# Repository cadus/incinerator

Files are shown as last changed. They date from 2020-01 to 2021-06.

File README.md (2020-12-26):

# Firmware & electronics for the CADUS incinerator

Furnace for the incineration of medical waste.

[][1]

  [PlatformIO CI]: https://github.com/cadus/incinerator/workflows/PlatformIO%20CI/badge.svg
  [1]: https://github.com/cadus/incinerator/actions?query=workflow%3A%22PlatformIO+CI%22

## [Project documentation on GitHub pages]

  [Project documentation on GitHub pages]: https://cadus.github.io/incinerator/

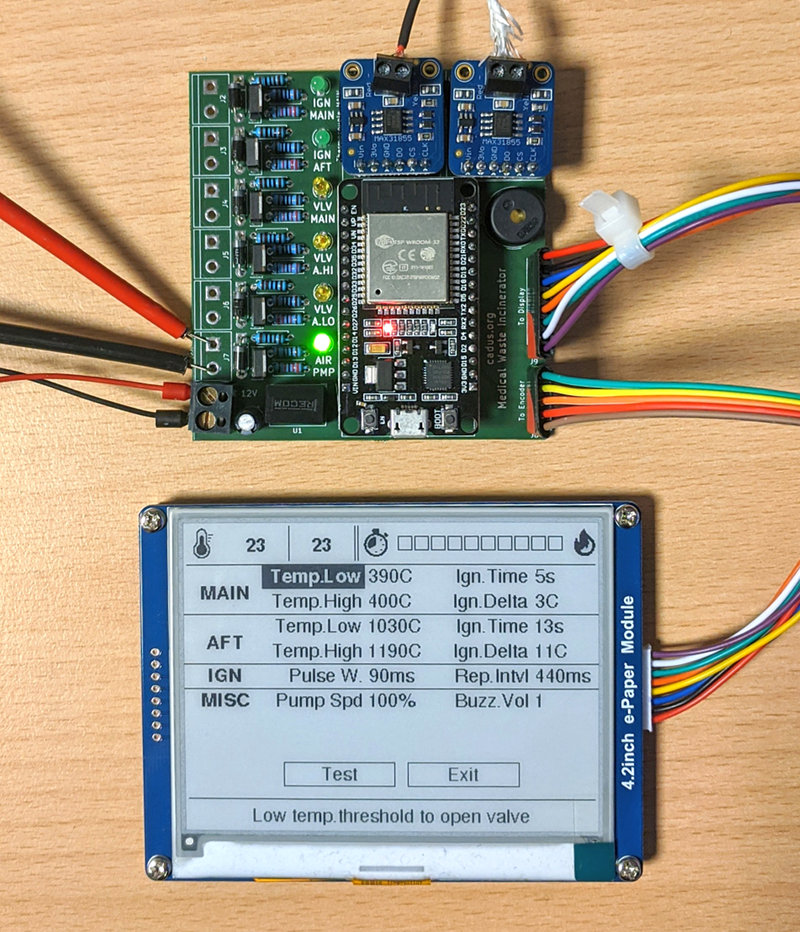
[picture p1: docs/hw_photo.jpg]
Hardware Photo


**Under construction / Work in progress**

Open Source Hardware

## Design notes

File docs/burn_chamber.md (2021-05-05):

# Burn chamber
The burn chamber is responsible for managing the burn process in one burn chamber, which includes triggering ignition, reading temperature and controlling gas flow via valves.

### Temperature control
The temperature is controlled with gas valves which can be ON or OFF (no gradual control). The main and afterburner chamber feature a single valve each (VALVE_MAIN,VALVE_AFT).

- When temperature sinks below T_MIN, VALVE_MAIN / VALVE_AFT is activated.
- When temperature rises above T_MAX, VALVE_MAIN / VALVE_AFT is deactivated.

### State machine
``` mermaid
stateDiagram-v2
  [*] --> start: Burn start requested
  start --> waitIgnition: Set gas valve, request ignition
  waitIgnition --> failed: Ignition failed
  failed --> [*]: Reset
  waitIgnition --> waitTemp: Ignition successful
  waitTemp --> burnHigh: T_MIN reached
  burnHigh --> burnLow: T > T_MAX
  burnLow --> waitBurnHigh: T < T_MIN, ignite again
  waitBurnHigh --> burnHigh: Ignition successful
  waitBurnHigh --> failed: Ignition failed
  burnHigh --> [*]: Reset
  burnLow --> [*]: Reset
```

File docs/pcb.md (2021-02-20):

# PCB schematic

SVG file

## Encoder wiring

SVG file

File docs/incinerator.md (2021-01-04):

# Incinerator
The incinerator is responsible for managing the overall burn process.

### Burn sequence
- Start burn process in afterburner to pre-heat it
- When afterburner has reached operating temperature, enable air pump and main burner.
- When main burner has reached operating temp., wait until burn time is elapsed.
- Switch off gas and wait until system has cooled down.

### State machine
``` mermaid
stateDiagram-v2
  [*] --> start: Burn start requested
  start --> waitAfterburner: Start afterburner
  waitAfterburner --> failureCoolDown: Aft. failed
  waitAfterburner --> startMain: Aft. temp. reached
  waitAfterburner --> abortCoolDown: User abort
  startMain --> waitMain: Start main burner
  waitMain --> burnActive: Main temp. reached
  waitMain --> failureCoolDown: Main failed
  waitMain --> abortCoolDown: User abort
  burnActive --> coolDown: Burn time elapsed
  burnActive --> failureCoolDown: Burner failed
  burnActive --> abortCoolDown: User abort
  coolDown --> [*]: System cooled down
  failureCoolDown --> [*]: System cooled down
  abortCoolDown --> [*]: System cooled down
```

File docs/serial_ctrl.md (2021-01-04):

# Serial control

On the ESP32 serial port, there's a simple command line interface implemented.

## Serial commands

| Command | Argument | Description |
|---|---|---|
| `TM` | deg. C | Simulate main burner temperature |
| `TA` | deg. C | Simulate afterburner temperature |
| `SS` | | Create screenshot |

## Temperature simulation

The temperature of the burn chambers can be simulated to facilitate testing of the incineration logic w/o actual burning.
To enable temperature simulation, the firmware needs to be built with `-DENABLE_TEMP_SIMULATION`.

### Temperature simulation tool

The script `temp_sim.py` can be used to conduct temperature simulation while testing.
The keys `e`, `r`, `d`, `f` and `u`, `i`, `j`, `k` lower or raise the main and afterburner temperature, respectively.

## Screenshots

`SS` creates a screenshot. It prints out a base64-encoding of a PNM file containing the current screen contents.

The base64 dump can be easily converted to a PNG file using the following shell snippet (needs imagemagick to work):
```
base64 -d | convert pnm:- screenshot.png
```

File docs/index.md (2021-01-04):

# CADUS incinerator
Furnace for the incineration of medical waste.

## Project scope
This project contains the firmware & schematic for the control module of the [CADUS](https://www.cadus.org) incinerator.

## Hardware
The control module is based on this ESP32 board: [DEBO JT ESP32 NodeMCU](https://www.reichelt.de/nodemcu-esp32-wifi-und-bluetooth-modul-debo-jt-esp32-p219897.html) similar to [DOIT ESP32 DEVKIT V1](http://elektro.turanis.de/html/prj135/esp32_pinout.png).  
KiCad project covering the schematic of the motherboard carrying the ESP32 is included in the `pcb` folder.

## Build Prerequisites
Install [PlatformIO IDE](https://platformio.org/platformio-ide) or [PlatformIO Core (CLI)](https://docs.platformio.org/en/latest/installation.html#installation-methods)  
PlatformIO will take care of the Arduino framework and third-party libraries.

## Build
PlatformIO IDE: Click "Build"  
PlatformIO CLI:
```
pio run
```

## Install
Connect ESP32 board via USB. Check the serial port assigned to the board, adapt `upload_port` in `platformio.ini`, if necessary.

PlatformIO IDE: Click "Upload"  
PlatformIO CLI:
```
pio run --target upload
```

## Update via esptool
Install esptool with `pip3 install --user esptool`.

Connect the processor module via USB and determine the USB serial port. (`/dev/ttyUSB0` in this example)

Update the firmware:
```
python3 -m esptool --port /dev/ttyUSB0 --baud 921600 write_flash 0x10000 firmware.bin
```

## Update via flasher
The flasher (distributed with releases) is a small wrapper around `esptool` and can be used for the update instead of calling `esptool` directly.

Using the flasher tool on windows:

* Install CP210x_VCP_Windows driver from https://www.silabs.com/developers/usb-to-uart-bridge-vcp-drivers
* Install Python3 https://www.python.org/downloads/windows/
  (Select "add python to PATH")
* Open terminal in flasher directory
* Enter "pip install esptool pyserial" (only necessary when doing this for the first time)
* Enter "flasher.py"
* Choose serial port (use the one called "Silicon Labs CP210x")
* Hold down the BOOT button on the processor board (right from the USB socket)
* Wait until flasher is finished

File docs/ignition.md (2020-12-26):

# Ignition module
Ignition is triggered from higher level control (burn chamber).

### Ignition control
Ignition coil is activated for a configurable time `ign_pulse_w`, this is repeated after a configurable delay `ign_repeat_itvl` until temperature has risen enough that a successful ignition can be assumed.

### Protection logic
Ignition control features a simple protection logic to make sure there's no gas flow when the gas is not burning. After ignition has started, the ignition module checks if temperature has risen by a configurable delta `ign_delta`. When a configurable timeout `ign_t` has elapsed w/o temperature rising, then the ignition module indicates that ignition has failed and the gas flow should be shut down.

### State machine
``` mermaid
stateDiagram-v2
  [*] --> setCoil: Ignition request
  setCoil --> waitPulse
  waitPulse --> resetCoil: ign_pulse_w elapsed
  resetCoil --> waitIgnition
  waitIgnition --> setCoil: ign_repeat_itvl elapsed
  waitIgnition --> success: Temp. raised
  waitIgnition --> failure: Timeout
  success --> [*]: Reset
  failure --> [*]: Reset
```

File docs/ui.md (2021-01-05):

# User interface

## Home screen

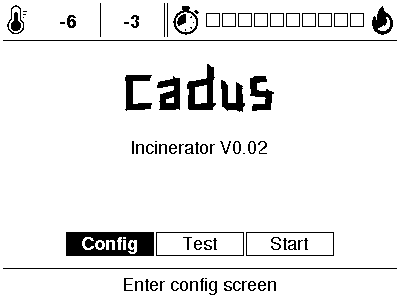
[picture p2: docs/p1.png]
home-screen


## Start screen

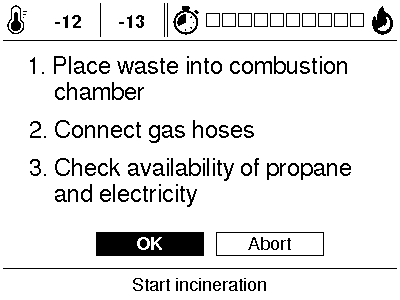
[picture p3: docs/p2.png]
start-screen


## Time entry

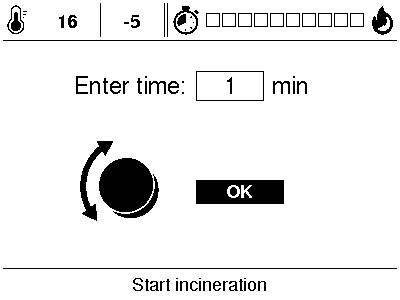
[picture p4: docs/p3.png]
time-entry


## Confirmation screen

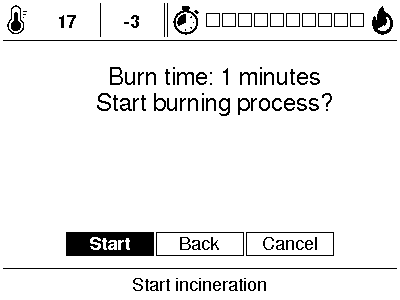
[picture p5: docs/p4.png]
confirmation-screen


## Burn screen

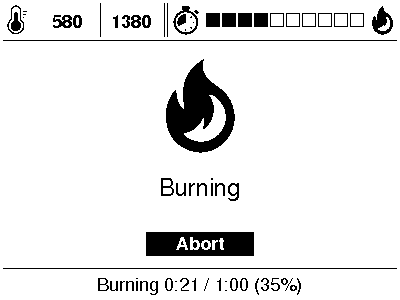
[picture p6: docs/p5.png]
burn-screen


## Cooldown screen
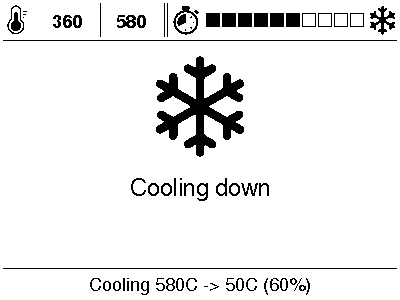
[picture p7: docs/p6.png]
cooldown-screen


## Cooldown finished
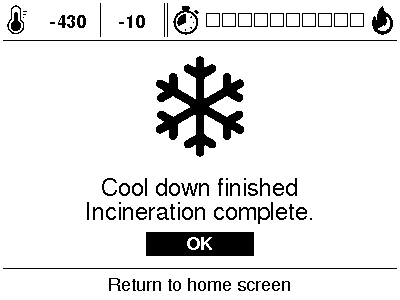
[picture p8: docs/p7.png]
cooldown-finished


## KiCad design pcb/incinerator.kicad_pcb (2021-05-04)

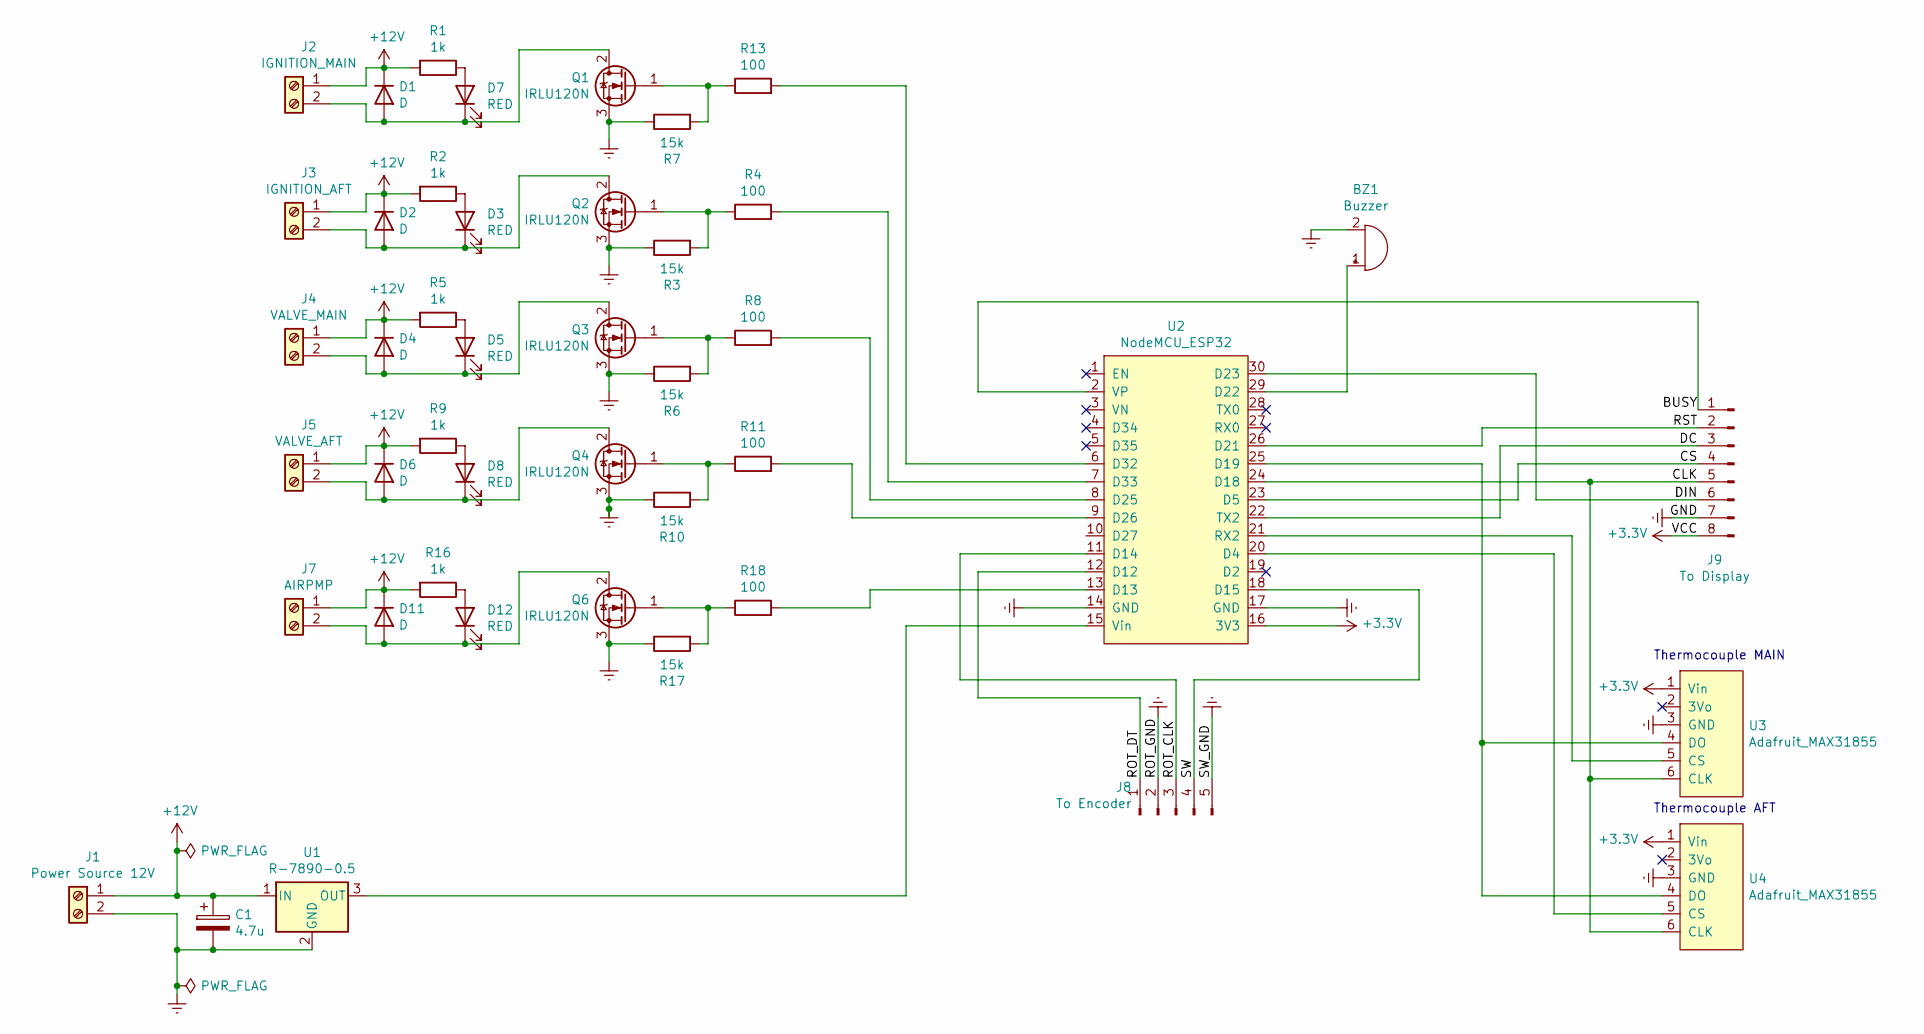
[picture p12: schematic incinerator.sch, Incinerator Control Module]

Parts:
BZ1: Buzzer; Buzzer_TDK_PS1240P02BT_D12.2mm_H6.5mm
C1: 4.7u; CP_Radial_D5.0mm_P2.50mm
D1, D2, D4, D6, D11: D; D_DO-41_P7.62mm_Custom
D3, D5, D7, D8, D12: RED; LED_D3.0mm_Custom
J1: Power Source 12V; TerminalBlock_bornier-2_P5.08mm
J2: IGNITION_MAIN; TerminalBlock_bornier-2_P5.08mm
J3: IGNITION_AFT; TerminalBlock_bornier-2_P5.08mm
J4: VALVE_MAIN; TerminalBlock_bornier-2_P5.08mm
J5: VALVE_AFT; TerminalBlock_bornier-2_P5.08mm
J7: AIRPMP; TerminalBlock_bornier-2_P5.08mm
J8: To Encoder; PinHeader_1x05_P2.54mm_Vertical
J9: To Display; PinHeader_1x08_P2.54mm_Vertical
Q1, Q2, Q3, Q4, Q6: IRLU120N; SIPAK_Vertical_Custom
R1, R2, R5, R9, R16: 1k; R_THT_D2.5mm_P7.62mm_Custom
R3, R6, R7, R10, R17: 15k; R_THT_D2.5mm_P7.62mm_Custom
R4, R8, R11, R13, R18: 100; R_THT_D2.5mm_P7.62mm_Custom
U1: R-7890-0.5; Converter_DCDC_RECOM_R-78E-0.5_THT
U2: NodeMCU_ESP32; ESP32_NodeMCU
U3, U4: Adafruit_MAX31855

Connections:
+3V3: J9.8, U2.16 (3V3), U3.1 (Vin), U4.1 (Vin)
+12V: C1.1, D1.1 (K), D2.1 (K), D4.1 (K), D6.1 (K), D11.1 (K), J1.1, J2.1, J3.1, J4.1, J5.1, J7.1, R1.2, R2.2, R5.2, R9.2, R16.2, U1.1 (IN)
/BUSY: J9.1, U2.2 (VP)
/CLK: J9.5, U2.24 (D18), U3.6 (CLK), U4.6 (CLK)
/CS: J9.4, U2.23 (D5)
/DC: J9.3, U2.22 (TX2)
/DIN: J9.6, U2.30 (D23)
/ROT_CLK: J8.3, U2.11 (D14)
/ROT_DT: J8.1, U2.12 (D12)
/RST: J9.2, U2.26 (D21)
/SW: J8.4, U2.18 (D15)
Earth: BZ1.2 (+), C1.2, J1.2, J8.2, J8.5, J9.7, Q1.3 (S), Q2.3 (S), Q3.3 (S), Q4.3 (S), Q6.3 (S), R3.1, R6.1, R7.1, R10.1, R17.1, U1.2 (GND), U2.14 (GND), U2.17 (GND), U3.3 (GND), U4.3 (GND)
unnamed: BZ1.1 (-), U2.29 (D22)
unnamed: D1.2 (A), D7.1 (K), J2.2, Q1.2 (D)
unnamed: D2.2 (A), D3.1 (K), J3.2, Q2.2 (D)
unnamed: D3.2 (A), R2.1
unnamed: D4.2 (A), D5.1 (K), J4.2, Q3.2 (D)
unnamed: D5.2 (A), R5.1
unnamed: D6.2 (A), D8.1 (K), J5.2, Q4.2 (D)
unnamed: D7.2 (A), R1.1
unnamed: D8.2 (A), R9.1
unnamed: D11.2 (A), D12.1 (K), J7.2, Q6.2 (D)
unnamed: D12.2 (A), R16.1
unnamed: Q1.1 (G), R7.2, R13.1
unnamed: Q2.1 (G), R3.2, R4.1
unnamed: Q3.1 (G), R6.2, R8.1
unnamed: Q4.1 (G), R10.2, R11.1
unnamed: Q6.1 (G), R17.2, R18.1
unnamed: R4.2, U2.7 (D33)
unnamed: R8.2, U2.8 (D25)
unnamed: R11.2, U2.9 (D26)
unnamed: R13.2, U2.6 (D32)
unnamed: R18.2, U2.13 (D13)
unnamed: U1.3 (OUT), U2.15 (Vin)
unnamed: U2.20 (D4), U4.5 (CS)
unnamed: U2.21 (RX2), U3.5 (CS)
unnamed: U2.25 (D19), U3.4 (DO), U4.4 (DO)

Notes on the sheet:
Thermocouple MAIN
Thermocouple AFT

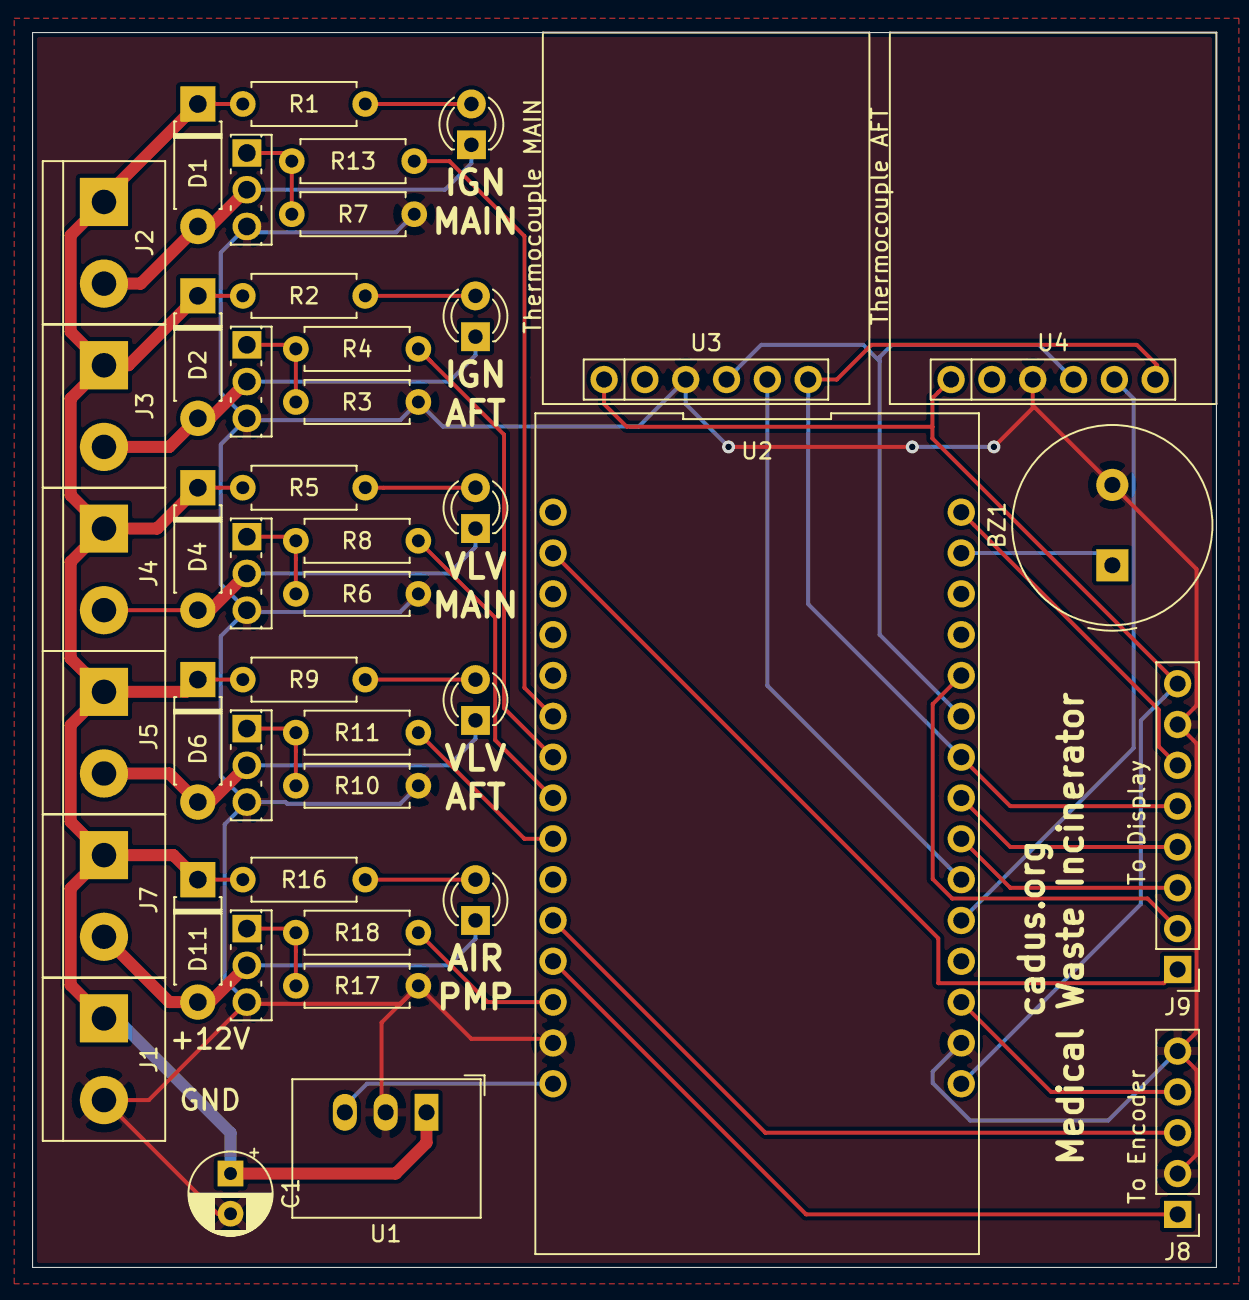
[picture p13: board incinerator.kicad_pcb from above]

Board: 2 copper layers, 73.7 x 76.8 mm, 44 parts (0 on the bottom side), 37 nets.

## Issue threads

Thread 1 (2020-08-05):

Documentation for building the burn-chamber?

hoijui, 2020-08-05:
Hello! :-)
We visited you last year (a delegation of two from OSEG), and I remembered this project. We are interested in it for possible future plans of an open, open source bio-lab.
I was wondering, if you may also have documentation and plans for building the hardware (apart form the electronics), as in.. the chamber I saw, comprised on metal and building-stones (at that time).
... and in case you don't have such documentation... do you plan to make it, and if not, would it be possible for someone of us to come by and document it? (taking photos, asking questions, ...)

patrislav1, 2020-08-08:
Hi,
The mechanical construction was done by Marinus Spatzier as part of his thesis, I think he doesn't follow this repository as it's firmware centered - however you can write him at marinusspatzier[AT]gmail[DOT]com and I think he'll be happy to share the construction details with you. Maybe it would also make sense to share them here in this repo later?

hoijui, 2020-08-09:
cool, thank you! :-)
I wrote him.

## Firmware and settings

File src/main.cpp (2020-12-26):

/*
 * SPDX-License-Identifier: GPL-3.0-or-later
 * This file is part of CADUS Incinerator, https://github.com/cadus/incinerator
 * Copyright (C) 2019-2020 Patrick Huesmann <info@patrick-huesmann.de>
 *
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
 * You should have received a copy of the GNU General Public License
 * along with this program.  If not, see <https://www.gnu.org/licenses/>.
 */

#include <Arduino.h>

#include "incinerator/incinerator.h"

#include "ui/buzzer.h"
#include "ui/debounced_encoder.h"
#include "ui/ui.h"

#include "util/sys_config.h"
#include "util/timeout.h"

#include "serial_ctrl.h"
#include "hw_config.h"
#include "version.h"

static void IRAM_ATTR timer_isr(void);
static hw_timer_t* timer = NULL;

static Ui ui;

void setup()
{
    Serial.begin(115200);

    sysconfig.init();

    // Register timer ISR at 4kHz (250us)
    timer = timerBegin(0, 80, true);
    timerAttachInterrupt(timer, timer_isr, true);
    timerAlarmWrite(timer, 250, true);

    // Give display some time to start up
    delay(100);
    ui.init();

    incinerator.init();

    timerAlarmEnable(timer);

    Serial.printf("Incinerator version %s, build date %s\r\n", gitversion, builddate);
}

// Lightweight tasks to run in the background
void background_task()
{
    incinerator.task();
    ui.backgroundTask();
    serial_ctrl_task();
}

// Called by display code, while waiting for display BUSY flag to reset
void GxEPD2_busyWaitCallback()
{
    background_task();
}

void loop()
{
    // UI task refreshes display every second (or on user input)
    // & calls background_task() while busy waiting for display
    ui.task();
    // Call background_task() explicitly, so it runs even if display wasn't refreshed.
    background_task();
}

static void IRAM_ATTR timer_isr(void)
{
    // every 250 us
    encoder_check_rotation();
    encoder_check_switch();

    static uint8_t count = 0;
    if (!(count++ & 3)) {
        // once per millisecond
        buzzer.task();
        Timeout::incrementMs();
    }
}

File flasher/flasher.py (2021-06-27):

#!/usr/bin/env python3

import argparse
import esptool
import serial
import sys

"""
Using the commandline parameters from "pio run -t upload -v"
"""

def esp_update(fwfile, port, baud):
    esptool.main(argv=[
        "--chip", "esp32",
        "--port", port,
        "--baud", str(baud),
        "--before", "default_reset",
        "--after", "hard_reset",
        "write_flash", "-z", 
        "--flash_mode", "dio", 
        "--flash_freq", "40m", 
        "--flash_size", "detect", 
        "0x1000", "bootloader_dio_40m.bin", 
        "0x8000", "partitions.bin",
        "0xe000", "boot_app0.bin", 
        "0x10000", fwfile
    ])

def port_chooser():
    comports = serial.tools.list_ports.comports()
    n_max = max(len(port.device) for port in comports)
    for n, port in enumerate(comports):
        s = port.device
        s += ' ' * (len(s) - n_max) + ' - ' 
        s += port.product or port.description or ''
        print(f'{n}: {s}')
    
    i = input(f'Choose port (0-{len(comports)-1}): ')
    try:
        i = int(i)
    except ValueError:
        i = -1

    if i < 0 or i >= len(comports):
        print('Abort')
        sys.exit(0)

    return comports[i].device

def main():
    parser = argparse.ArgumentParser(
        description='CADUS incinerator flash tool'
    )
    parser.add_argument('-f', '--fwfile',
                        type=str,
                        default='firmware.bin',
                        help='Firmware file'
    )
    parser.add_argument('-p', '--port',
                        type=str,
                        help='Serial port'
    )
    parser.add_argument('-b', '--baud',
                        type=int,
                        default=921600,
                        help='Baud rate'
    )
    args = parser.parse_args()
    
    port = args.port or port_chooser()
    esp_update(args.fwfile, port, args.baud)


if __name__ == '__main__':
    main()

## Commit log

2019-11-18 added support for encoder rotation
2019-11-18 removed former encoder code, added s/w debouncing
2019-11-18 removed encoder_switch_isr() to handle switch in timer isr
2019-11-18 cleaned up encoder functions and moved to dedicated module
2019-11-18 moved MAX cs and added LEDs
2019-11-18 Show temperature history
2019-11-18 Changed icon names to upper case
2019-11-24 Added encoder value display
2019-11-24 Ported display code to ESP32
2019-11-24 added ESP32 pinout
2019-11-24 added ESP32 board schematic
2019-11-24 Added KiCad schematic
    [incinerator.kicad_pcb, incinerator.sch]
2019-11-24 Completed schematic
    [incinerator.sch]
2019-11-24 Moved pcb file up one level
    [incinerator.kicad_pcb, incinerator.sch]
2019-11-24 ported icons to esp32
2019-11-24 ported icon create script to esp32
2019-11-24 Added support for int. LED
2019-12-04 Changed thermocouple PCB to generic off-brand one
    [incinerator.sch]
2019-12-06 added led pwm test code
2019-12-06 added buzzer object & removed LED PWM test
    [buzzer.cpp, main.cpp]
2019-12-06 added support for buzzer volume (duty cycle)
    [buzzer.cpp, main.cpp]
2019-12-06 Moved LED_INT to buzzer class
    [buzzer.cpp]
2019-12-06 Added skeleton code for burn chamber & incinerator
    [burn_chamber.cpp]
2019-12-11 Add support for buzzer volume config
    [buzzer.cpp]
2019-12-12 Added convenience functions to avoid using getTextBounds() directly
    [screen.cpp]
2019-12-13 Fixed copy paste bug
    [buzzer.cpp]
2019-12-13 consolidated print functions and added bitfield flags
2019-12-13 ISR-safe ledcWrite() for buzzer
    [buzzer.cpp]
2019-12-14 Added generic framework for interactive screens
2019-12-14 Added push button handler callback
2019-12-14 Added wraparound option for encoder input
2019-12-14 Print burn chamber temperatures in bold
    [screen.cpp]
2019-12-14 Print config categories in bold
2019-12-15 Removed backup capacitor (needs proper charging circuit)
    [incinerator.sch]
2019-12-15 Moved I/O pins due to pin restrictions
    [incinerator.sch]
2019-12-15 Added air pump
2020-01-03 Removed PWM test code
2020-01-03 Removed air pump & burn chambers from global namespace
    [air_pump.cpp, main.cpp, screen.cpp]
2020-01-03 Give names to burners / iginitions / thermocouples
    [burn_chamber.cpp, ignition.cpp]
2020-01-03 Added option to draw push button w/o enclosing rect
2020-01-04 clang-format: Align after open bracket
2020-01-05 Add low side MOSFETs for furnace control
    [incinerator.sch]
2020-01-05 Include schematic as SVG in mkdocs page
2020-01-05 Update DCDC info & added support capacitor
    [incinerator.sch]
2020-01-06 Added project-specific KiCad library for breakout boards
    [incinerator.sch]
2020-01-07 Added KiCad symbol for thermocouple breakout board
    [incinerator.sch]
2020-01-07 Add author & license info to schematic
    [incinerator.sch]
2020-01-07 Added ctrl leds to furnace terminals
    [incinerator.sch]
2020-01-07 reassigned symbols
    [incinerator.sch]
2020-01-07 Update schematic in docs
2020-01-07 Add documentation for incinerator & burn chamber
2020-01-08 Add support for Alps encoder
2020-01-10 Add power flags to satisfy KiCad electrical rule check
    [incinerator.sch]
2020-01-10 Fix symbol for thermocouple breakout board & added N/C marks to satisfy electrical rule check
    [incinerator.sch]
2020-01-10 Add connector to interface the encoder/switch
    [incinerator.sch]
2020-01-10 Re-annotated symbols
    [incinerator.sch]
2020-01-10 Added custom footprints
2020-01-10 Assigned footprints
    [incinerator.sch]
2020-01-10 started layout (WIP)
    [incinerator.kicad_pcb, incinerator.sch]
2020-01-10 First draft of PCB layout
    [incinerator.kicad_pcb, incinerator.sch]
2020-01-10 Updated schematic in docs
2020-01-11 removed breadboard traces from pcb
    [incinerator.kicad_pcb]
2020-01-11 reduced THT footprints from 10.16 to 7.62mm
    [incinerator.sch]
2020-01-12 re-worked & shrinked PCB
    [incinerator.kicad_pcb, incinerator.sch]
2020-01-16 Add PCB infos
    [incinerator.kicad_pcb]
2020-01-16 aligned track width/clearance w/ smartprototyping.com & added settings for power tracks
    [incinerator.kicad_pcb]
2020-01-16 increased pad sizes for breakout boards
2020-01-16 updated pad sizes in PCB
    [incinerator.kicad_pcb]
2020-01-16 added traces & ground planes
    [incinerator.kicad_pcb, incinerator.sch]
2020-01-16 Created gerber / drill files
    [incinerator-B_Cu.gbr, incinerator-B_Mask.gbr, incinerator-B_SilkS.gbr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]
2020-01-27 Swapped encoder clock & data pins
    [hw_config.h]
2020-01-27 Increased drill sizes for breakout boards, so they can be mounted directly
    [incinerator.kicad_pcb]
2020-01-27 Added Open Source Hardware logo
    [incinerator.kicad_pcb]
2020-02-03 Refactored power switch channels to KiCad sub-sheet
    [incinerator.sch, switch_channel.sch]
2020-12-06 Add IgnMainTest button
2020-12-07 Add ignition test buttons for both ignitions
2020-12-08 Add valves to burn chamber
    [burn_chamber.cpp]
2020-12-08 Add valve test buttons to test screen
2020-12-24 Add skeleton for BurnChamber state machine
    [burn_chamber.cpp]
2020-12-25 Add burn chamber state machine
    [burn_chamber.cpp]
2020-12-25 Rearrange test screen, make room for burner test buttons
2020-12-26 Make burn chambers / air pump public
    [screen.cpp]
2020-12-26 Add serial_ctrl and option for temperature simulation
2020-12-26 Add 'temperature simulation' tool
2020-12-26 Add burn chamber test buttons
    [burn_chamber.cpp, ignition.cpp]
2020-12-26 Add waitBurnHigh state to check re-ignition at lower end of temperature range
2020-12-29 Add incinerator test button
2020-12-29 Show help text only on item change (avoid log messages being hidden by help text)
    [interactive_screen.cpp]
2020-12-30 Fix pre- & post-build scripting
    [copy_build.py, gitversion.py]
2021-01-04 Add incinerator::abort() and dedicated cooldown modes for abort & failure
    [screen.cpp]
2021-02-20 Add encoder wiring information
2021-04-21 Fix link error w/ recent arduinoespressif32 framework
    [buzzer.cpp]
2021-05-04 Revert schematic to earlier version to keep connection to PCB footprints
    This reverts commit a7a99f7f60577d9f8a86e54cb3c3f2c49a53cb32.
    [incinerator.sch, switch_channel.sch]
2021-05-04 pcb: Delete AFT.LO channel
    Rearrange screw connectors
    [incinerator.kicad_pcb, incinerator.sch]
2021-05-05 Remove 2nd afterburner valve in code and documentation
2021-05-05 docs: Update PCB SVG
2021-05-05 Remove 2nd afterburner valve from test screen

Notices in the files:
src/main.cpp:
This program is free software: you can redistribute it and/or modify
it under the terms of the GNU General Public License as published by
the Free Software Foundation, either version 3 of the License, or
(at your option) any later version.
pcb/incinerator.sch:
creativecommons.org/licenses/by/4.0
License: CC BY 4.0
